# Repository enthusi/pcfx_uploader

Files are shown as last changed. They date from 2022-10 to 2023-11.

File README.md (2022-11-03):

# PCFX Uploader
transmitting data from PC to a NEC PC-FX via microcontroller in GPL v3 licence.

## Build
*microcontroller_code* contains the firmware in assembly for the LonganNano.\
*RP2040_device* contains information on how to build an alternate microcontroller board, and firmware (C & PIO Assembly) for this board.\
*pc_code* with the python script to upload data via UART connection.\
*pcfx_code* contains the client on NEC PC-FX side in v810 assembly (`make cd` will build an CD bin/cue image).

To build just type ```make``` in the corresponding folder, or launch the script, given that you have the following tools in your path:\
[RV32 Assembler Bronzebeard](https://github.com/theandrew168/bronzebeard)\
[v810 binutils](https://github.com/jbrandwood/v810-gcc)\
[pcfx-tools](https://github.com/jbrandwood/pcfxtools)

The RP2040 device is based on pico-sdk version 1.4.0.  To build, execute the command within 'build_xiao.sh', then 'cd build', and 'make'\
[pico-sdk](https://github.com/raspberrypi/pico-sdk)

## Summary
- the code on the PCFX side expects a magic word, start-address, execution-address and data length
- the code on the microcontroller mimics a PC-FX controller and sends all 32 keypad bits in the PC-FX specific protocol
- the code on the PC side simply connects to the microcontroller via UART
- The overall transmission speed is close to the UART limit despite a couple of extended wait loops on the PC-FX side. That could be optimized for speed if one really wanted to.

## Setup

### Longan Nano
This setup was used for initial development. The RP2040-based board will become the main supported plattform.\
The Longan Nano is hooked up to Port2 of the PC-FX via 3V-5V level shifts (though it _should_ be 5V tolerant)\
It uses 5 lines: GND, VCC, CLOCK, LATCH and DATA.\
The PC-FX pulls the LATCH line to low (0 Volts) when it wants more data to come in.
Then it sends a quick clock signal HIGH,LOW,HIGH,...\
The microcontroller senses that LATCH line, if it gets low, waits for it to get high then senses the CLOCK line and makes sure to put the proper
signal on the output DATA depending on the state of your data bit (0 or 1). Initially, I tested that in C on the raspberry PI with _some_ success.
But it became clear that it would be too instable. Then I went for a microcontroller (with only ~100 Mhz) in C. That worked but I wasn't totally happy.
Then I recoded the microcontroller in plain assembly (32bit RiscV, not too different from the PC-FX's native v810 CPU btw).
The PC connects via UART to the native UART lines of the Longan Nano.

### RP2040-based board
This operates the same as the Longan Nano, except observes the /OE line, which was found to control the direction of data on the DATA line (which
means that data can flow both *to* and *from* the PC-FX).
When this signal is high, the PC-FX sends data, so the microcontroller's output data line is tri-stated, and the signal is routed to an
alternate pin to be used for inbound data.
PIO assembly language is used for signal switching at high speeds, as this is its strength; the 'C' code merely acts as a traffic manager
for the data.
On this board, the USB port is used a virtual COM port, in order to keep the parts count to a minimum.

## Demonstration
YouTube recording of initial LonganNano variant:\
NEC PC-FX uploader by PriorArt (https://www.youtube.com/watch?v=flS91IILcIk "NEC PC-FX uploader by PriorArt")

## Credits
- PC-FX code and Longan board design and code: *Martin 'enthusi' Wendt* [PriorArt](https://priorartgames.eu)
- RP2040 board design and code: *David Shadoff*

the folder *pc_code* contains the PC-FX binary `mandelbrot` from
[PC-FX Mandelbrot](https://github.com/enthusi/pcfx_fractal) which you can use to send as an example `python pysend.py mandelbrot`.\
See also: [PriorArt website](https://priorartgames.eu/2022/10/03/demo-mandelbrot-for-nec-pc-fx/)

## Research
[David Shadoff](https://github.com/dshadoff) tested the signals from '[test data line release'](https://github.com/enthusi/pcfx_uploader/releases/tag/testing_output) based on a RP2040 setup with his logic analyzer and confirms our expectation, that the data line is indeed bidirectional. Also the OE signal change flags the used direction.\
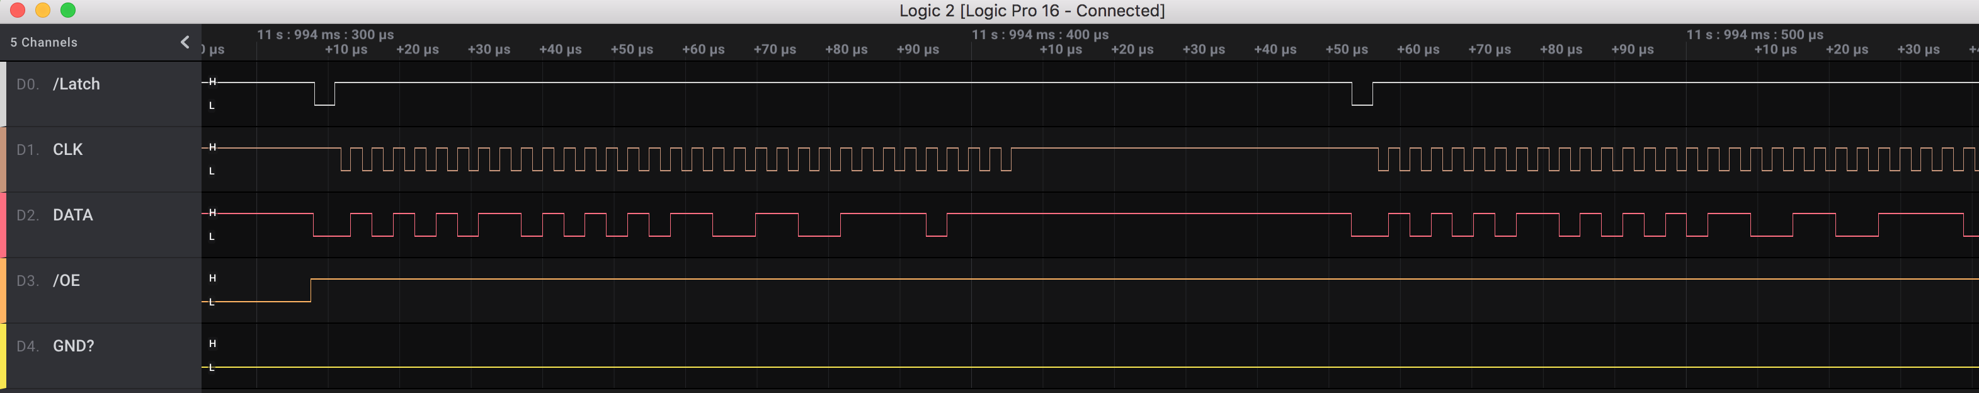
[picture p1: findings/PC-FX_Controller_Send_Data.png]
Logic analyzer


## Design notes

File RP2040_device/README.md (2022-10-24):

# PCFX Uploader RP2040 Device

## Overview

This section of the repository includes PC Board designs and instructions for building a PC-FX communications device, and
also includes the firware in order to work in concert with the PC-FX and PC components elsewhere in this repository.
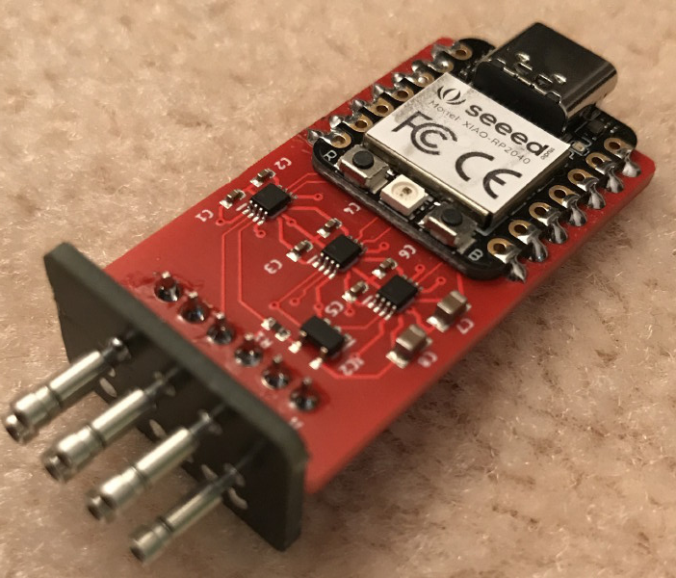
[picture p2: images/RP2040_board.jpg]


## PC Boards and Assembly

I designed all boards using the free version of EAGLE (2-layer, less than 100mm on both X- and Y- axes).
The gerbers are included in this repository, in case you want to get your own set made.

I have included the gerbers and relevant bom.csv and assembly.csv files to get these boards
assembled by JLCPCB, but you will still need the following parts:
- (1) Seeed Studio XIAO RP2040 microcontroller board
- (1) 6-pin right-angle through-hole pin header with 0.1" spacing.
- (7) Mill-Max Manufacturing part number 4401-0-15-80-18-27-04-0 "Receptacle with a standard tail" for creating a custom controller connector.
These are available at Digi-Key/Mouser.

You may also want to use male/female pin header sockets in case you need to remove the microcontroller board.
I recommend using short/low-profile header sockets in this case.

... These boards are solderable along the castellation, which is the recommended approach for assembly.

### Steps to assembly - Connector Board

Soldering the connector has a slightly more complicated process than the microcontroller board.  It's best not to have the pins penetrate all
the way through the board.  This is how I do it:
1. Insert the 7 Mill-Max connector pins into the PC-FX connector; you can use a pair of needle-nose pliers to assist in positioning.
2. Make sure to have one or two strands of speaker wire between the rows of pins; these will be used to extract the connector when
soldering is complete, but this wire should not be soldered to any part of the connector.
3. Position the connector board on top of the pins so that the silkscreen printing is facing up. Allow the pins to penetrate the holes slightly
but try to have them remain nearly flush with the PC board.
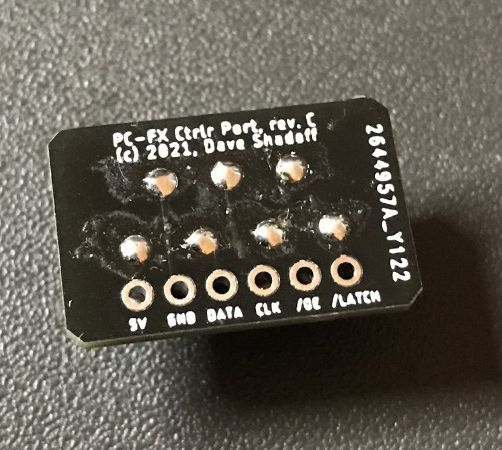
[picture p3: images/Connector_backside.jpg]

4. Ensure that the empty row of pins (which we will use for the right-angle pin headers) is not so close to the PC-FX; we would not want
them to be shorted by the slightly-visible metal faceplate when inserted.
5. Solder the pins in place
6. Use the wire to carefully extract the connectr assembly.
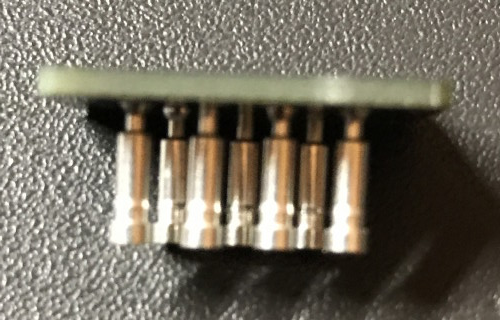
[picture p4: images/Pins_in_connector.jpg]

7. For the right-angle pin header, use angle clippers to remove some of the height of the pins so that they don't emerge through the
other side of the board when inserted.  The board should be 1.6mm thick; roughly 1.2mm-1.5mm of pin should be sufficient.
8. Solder the pin headers into place, with the long end facing inward; these will hold the main board in place.
9. Keep the solder on these holes as flat as possible; there is an opportunity to apply nail polish or some other NON-CONDUCTIVE
coating to ensure that they don't get shorted out by any metal hear the connector socket.

### Steps to assembly - RP2040 Board

1. Position the Seed RP2040 board on the top side carrier board (where other parts are also mounted), such that the holes are aligned
(you may wish to use a pin header or two to anchor it in place). Solder the boards together at the castellation as shown in the photo.
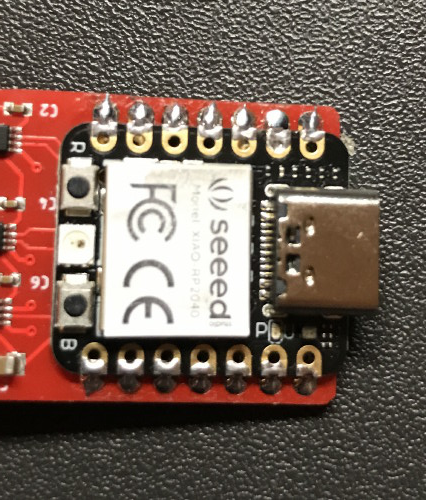
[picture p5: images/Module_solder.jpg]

2. Insert the headers from the connector board through the holes on the RP2040 board.  Be careful to ensure that the pins are on the
opposite side from the parts (i.e. the pins seem to "emerge" upwards when looking at the 'top' of the board where the parts are mounted).
This connection should be tight enough that the pins can hold the board in place.
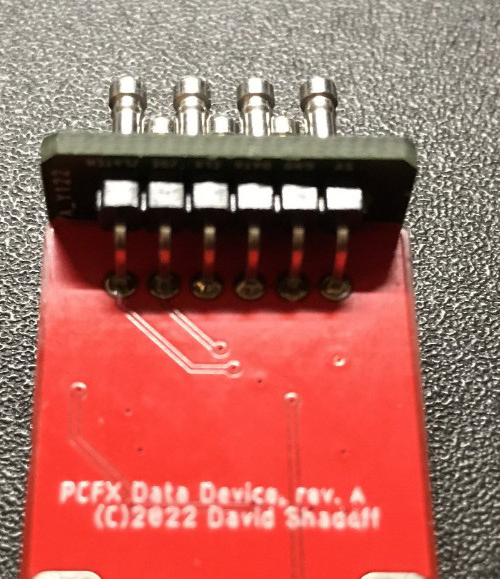
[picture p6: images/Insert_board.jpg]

3. With the board positioned roughly midway between the rows of the connector pins, solder the header pins into place.
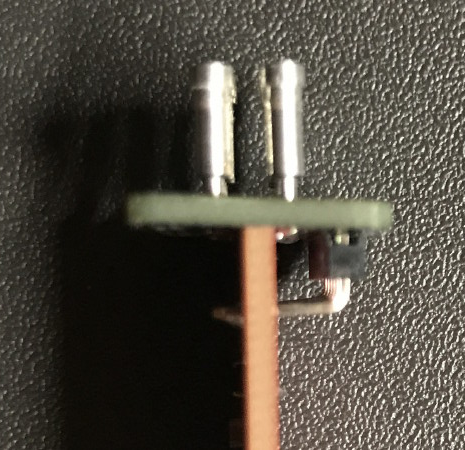
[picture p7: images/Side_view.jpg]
Top View

4. Program the microncontroller board accroudng to the steps in "Programming the Microcontroller Board" below.

## Source Code

### Compilation

This code was built to use Pico-SDK version 1.4.0, which may not be the newest version when you read this, but shouldn't have any
features which will change in futue versions (although it requires some components which were only made available in 1.4.0, so is
not backward-compatible).

pico_sdk_import.cmake is from the SDK, but is required by CMake (and thus replicated here)

This is based on the TinyUSB Host HID example, and since this often changes (required by refactoring of
the Host HID code), the initial commit baseline is the source ocde of that example.

To build the source, first ensure that you have the right version of the RaspberryPi/piso-sdk installed.
As this board targets the Seeed Studio XIAO RP2040 board, you should run the "make_xiao.sh" script (under UNIX).
Then, "cd build" and "make".

### Programming the Microcontroller Board

I have also included a release version of the program as a uf2 file in the releases/ folder.

To put the device into BOOTSEL mode, the board must be rebooted with the 'Boot' button pressed.  This can be done one of two ways:
1. Press and hold the button marked as 'B' (boot) while the USB is connected to a computer (and then release after power is applied), OR
2. Connect the USB to a computer, then press and hold the button marked as 'B' (boot), and while continuing to hold that button, press and
release the button marked as 'R' (reset).
The board will reboot in DFU mode, and will present itself as a USB drive to the host PC.

Then, just drag and drop the .uf2 file onto the USB drive which is presented.

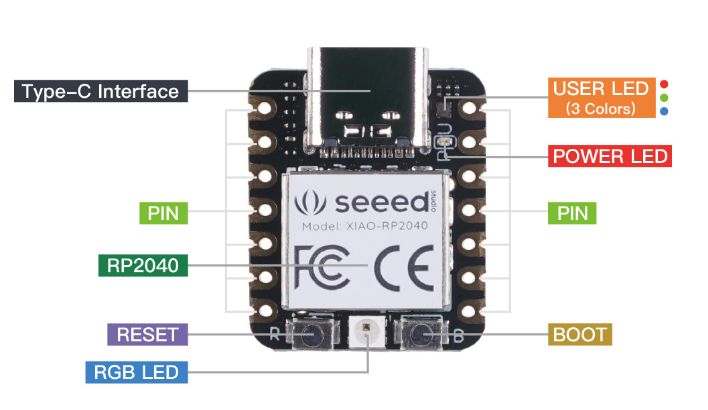
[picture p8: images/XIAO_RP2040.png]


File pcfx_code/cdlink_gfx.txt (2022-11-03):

binary loader_gfx
name framework
maker enthusi
makerid n2c
date 20220728
country 1
version 1

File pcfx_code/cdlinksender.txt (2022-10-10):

binary sender
name framework
maker enthusi
makerid n2c
date 20221010
country 1
version 1

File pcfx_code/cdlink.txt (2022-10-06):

binary loader
name framework
maker enthusi
makerid n2c
date 20220728
country 1
version 1

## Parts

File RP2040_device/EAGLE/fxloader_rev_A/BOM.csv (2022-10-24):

Qty | Designator | Footprint | Comment | LCSC Part # (optional) | Description (optional)
1 | J1 | 1X06_NO_SILK | Do not mount | Do not mount | Multi connection point. Often used as Generic Header-pin footprint for 0.1 inch spaced/style header connections
1 | J5 | 1X07_LONGPADS_OFFSET | Do not mount | Do not mount | Multi connection point. Often used as Generic Header-pin footprint for 0.1 inch spaced/style header connections
1 | J4 | 1X07_LONGPADS_OFFSET_B | Do not mount | Do not mount | Multi connection point. Often used as Generic Header-pin footprint for 0.1 inch spaced/style header connections
6 | C1, C2, C3, C4, C5, C6 | C0402 | 100nF 16V | C1525 | Samsung CL05B104KO5NNNC 100nF 16V 0402
2 | C7, C8 | C0805 | 10uF 25V | C15850 | Samsung CL21A106KAYNNNE 10uF 25V 0805
1 | R1 | R0402 | 330R | C25104 | Uniroyal Elec 0402WGF3300TCE 0402
1 | IC2 | SOT-23-5 | SN74AHCT1G125DBVR | C7484 | 74AHCT Single Tri-state Bus Buffer SOT23 SN74AHCT1G125DBVR, Bus Buffer, HCT, 8.5 ns@ 50 pF, 8mA 4.5 ??? 5.5 V 5-Pin SOT-23
3 | IC1, IC3, IC4 | VSSOP-8_2.0x2.3x0.5P | SN74LVC2T45DCUR | C15741 | 2-Bit Bus Transceiver, Translation VSSOP-8_2x2.3x05P SN74LVC2T45DCTR, Voltage Level Translator, Bus Transceiver LVC, 3-State 1.65

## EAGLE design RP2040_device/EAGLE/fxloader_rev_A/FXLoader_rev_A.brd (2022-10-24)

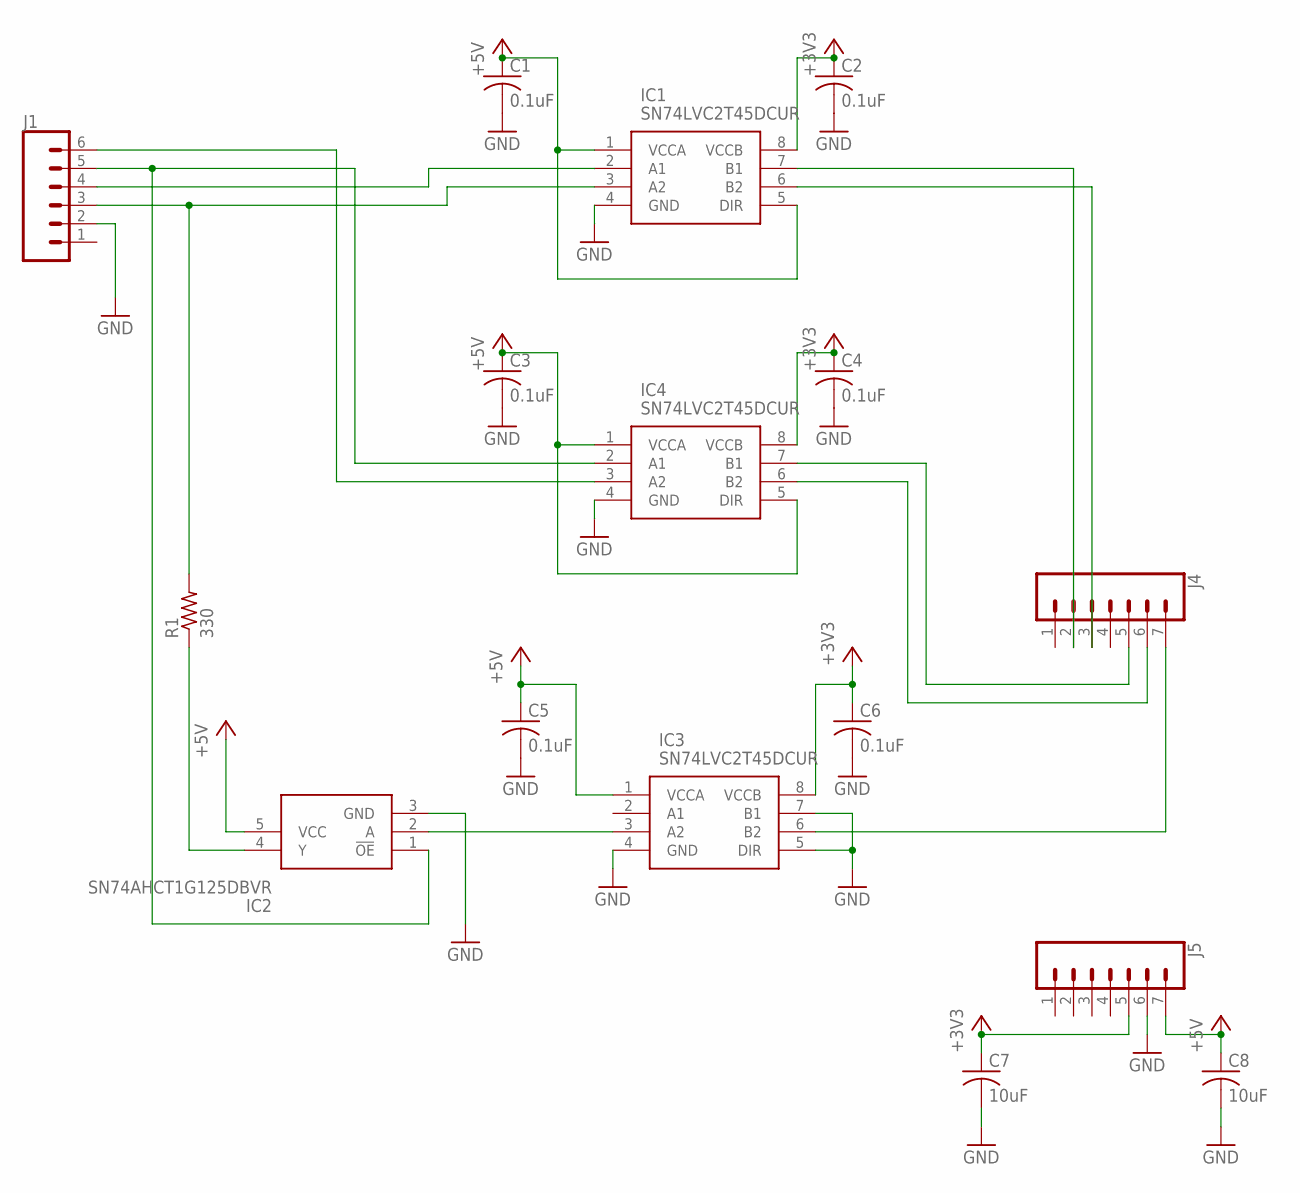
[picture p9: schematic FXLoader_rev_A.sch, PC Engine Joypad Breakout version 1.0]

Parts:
C1, C2, C3, C4, C5, C6: 0.1uF; C0402
C7, C8: 10uF; C0805
IC1, IC3, IC4: SN74LVC2T45DCUR; SOP50P310X90-8N
IC2: SN74AHCT1G125DBVR; SOT95P280X145-5N
J1: CONN_06NO_SILK_FEMALE_PTH; 1X06_NO_SILK
J4: CONN_071X07_LONGPADS_OFFSET_B; 1X07_LONGPADS_OFFSET_B
J5: CONN_071X07_LONGPADS_OFFSET; 1X07_LONGPADS_OFFSET
R1: 330; R0402

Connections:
+3V3: C2.1, C4.1, C6.1, C7.1, IC1.8 (VCCB), IC3.8 (VCCB), IC4.8 (VCCB), J5.5
+5V: C1.1, C3.1, C5.1, C8.1, IC1.1 (VCCA), IC1.5 (DIR), IC2.5 (VCC), IC3.1 (VCCA), IC4.1 (VCCA), IC4.5 (DIR), J5.7
CLK: IC1.2 (A1), J1.4
DATA: IC1.3 (A2), J1.3, R1.2
GND: C1.2, C2.2, C3.2, C4.2, C5.2, C6.2, C7.2, C8.2, IC1.4 (GND), IC2.3 (GND), IC3.4 (GND), IC3.5 (DIR), IC3.7 (B1), IC4.4 (GND), J1.2, J5.6
unnamed: IC2.2 (A), IC3.3 (A2)
unnamed: IC1.7 (B1), J4.2
unnamed: IC3.6 (B2), J4.7
unnamed: IC2.4 (Y), R1.1
unnamed: IC4.3 (A2), J1.6
unnamed: IC4.6 (B2), J4.6
unnamed: IC1.6 (B2), J4.3
unnamed: IC4.7 (B1), J4.5
W/R: IC2.1 (!OE), IC4.2 (A1), J1.5

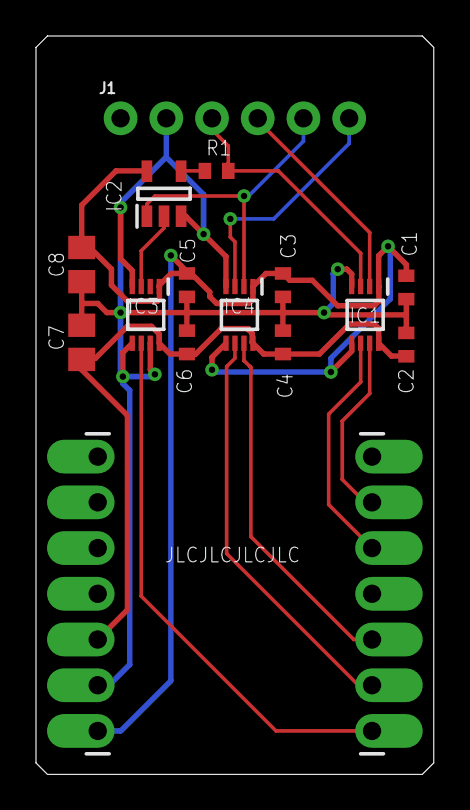
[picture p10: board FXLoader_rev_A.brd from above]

Board: 2 copper layers, 22.1 x 41.0 mm, 16 parts (0 on the bottom side), 14 nets.

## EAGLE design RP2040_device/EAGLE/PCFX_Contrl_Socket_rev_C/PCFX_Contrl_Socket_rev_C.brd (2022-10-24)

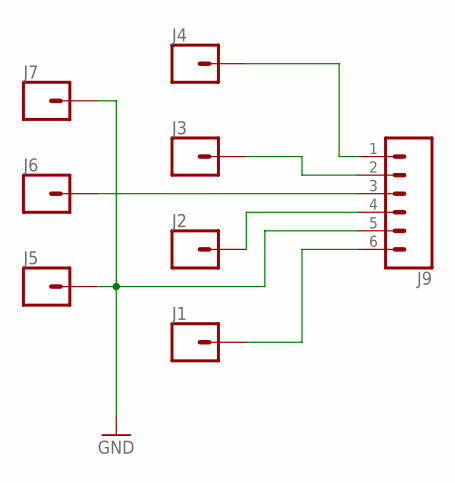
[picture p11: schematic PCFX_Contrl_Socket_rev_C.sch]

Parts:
J1, J2, J3, J4, J5, J6, J7: CONN_01PTH_NO_SILK_YES_STOP; 1X01_NO_SILK
J9: CONN_06NO_SILK_FEMALE_PTH; 1X06_NO_SILK

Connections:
GND: J5.1, J7.1, J9.5
unnamed: J4.1, J9.1
unnamed: J3.1, J9.2
unnamed: J6.1, J9.3
unnamed: J2.1, J9.4
unnamed: J1.1, J9.6

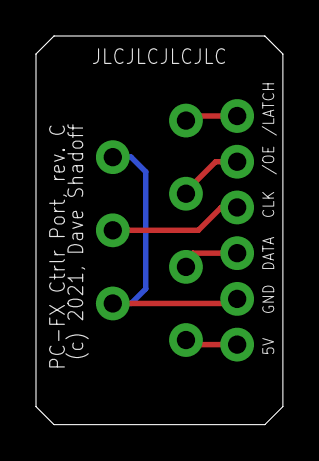
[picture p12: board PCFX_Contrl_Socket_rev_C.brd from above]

Board: 2 copper layers, 13.7 x 21.6 mm, 8 parts (0 on the bottom side), 6 nets.

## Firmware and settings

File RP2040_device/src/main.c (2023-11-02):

/**
 * Copyright (c) 2020 Raspberry Pi (Trading) Ltd.
 *
 * SPDX-License-Identifier: BSD-3-Clause
 */

#include <stdio.h>

#include "pico/stdlib.h"
#include "hardware/pio.h"
#include "hardware/uart.h"
#include "pcfxplex.pio.h"
#include "clock.pio.h"
#include "ws2812.pio.h"

//--------------------------------------------------------------------+
// MACRO CONSTANT TYPEDEF PROTYPES
//--------------------------------------------------------------------+


#define UART_ID uart0
#define BAUD_RATE 115200

// We are using pins 0 and 1, but see the GPIO function select table in the
// datasheet for information on which other pins can be used.
#define UART_TX_PIN 0
#define UART_RX_PIN 1


#define IS_RGBW false
#define NUM_PIXELS 1

#define LED_UART_TO_MCU   urgb_u32(0,10,0)   // green
#define LED_MCU_TO_PCFX   urgb_u32(0,0,10)   // blue
#define LED_PCFX_TO_MCU   urgb_u32(10,0,0)   // red
#define LED_MCU_TO_UART   urgb_u32(10,10,0)  // yellow
#define LED_EXEC          urgb_u32(3,0,3)    // purple
#define LED_IDLE          urgb_u32(5,5,5)    // light white


#ifdef SEEED_XIAO_RP2040         // else assignments for Seed XIAO RP2040 board

#define DATAIN_PIN      6
#define CLKIN_PIN       DATAIN_PIN + 1
#define DATAOUT_PIN     26
#define LATCHIN_PIN     27
#define READWRITE_PIN   28       // determines data direction

#define PICO_LED1       17
#define PICO_LED2       16
#define PICO_LED3       25
#define PICO_LED_ON     0
#define PICO_LED_OFF    1

#define WS2812_PIN PICO_DEFAULT_WS2812_PIN

#endif


uint32_t magic_word = 0x12345678; // for deploying initial program

uint32_t read_word = 0x44414552;  // READ
uint32_t rdbr_word = 0x52424452;  // RDBR
uint32_t writ_word = 0x54495257;  // WRIT
uint32_t wrbr_word = 0x52425257;  // WRBR
uint32_t exec_word = 0x43455845;  // EXEC
uint32_t call_word = 0x4C4C4143;  // CALL

uint32_t start_addr = 0x00008000;
uint32_t num_bytes  = 0;

uint32_t payload_data[32768];


PIO pio, pioled;
uint sm1, sm2, smled;   // sm1 = plex, sm2 = clock


//// WS2812 "Neopixel" protocol transport
//
static inline void put_pixel(uint32_t pixel_grb) {
    pio_sm_put_blocking(pioled, smled, pixel_grb << 8u);
}

static inline uint32_t urgb_u32(uint8_t r, uint8_t g, uint8_t b) {
    return
            ((uint32_t) (r) << 8) |
            ((uint32_t) (g) << 16) |
            (uint32_t) (b);
}

/// UART
//
uint8_t uart_get_char(void)
{
int inchar;

   inchar = getchar_timeout_us(0);
//   inchar = uart_getc(UART_ID);

   while (inchar == PICO_ERROR_TIMEOUT)
      inchar = getchar_timeout_us(0);

   return((uint8_t)inchar);
}

//
// Find the 'magic word' by scanning the UART stream first for the initial byte,
// and then checking whether the next 3 bytes form the word; if not, then start over
//
uint32_t uart_get_magic_word(void)
{
uint32_t uart_word = 0;
uint8_t  uart_byte = 0;

   while (uart_word != magic_word) {
      uart_word = 0;

      while (uart_byte != (uint8_t)(magic_word & 0xff))
         uart_byte = uart_get_char();

      uart_word |= uart_byte;

      uart_byte = uart_get_char();
      uart_word |= (uart_byte << 8);

      uart_byte = uart_get_char();
      uart_word |= (uart_byte << 16);

      uart_byte = uart_get_char();
      uart_word |= (uart_byte << 24);
   }

   return(uart_word);
}

uint32_t uart_get_cmd(void)
{
uint32_t uart_word = 0;
uint8_t  uart_byte = 0;
bool     word_match = false;

   while (!word_match)
   {
     uart_byte = uart_get_char();

     uart_word = ((uart_word >> 8) & 0xffffff) | (uart_byte << 24);

     if ((uart_word == read_word) ||
         (uart_word == rdbr_word) ||
         (uart_word == writ_word) ||
         (uart_word == wrbr_word) ||
         (uart_word == exec_word) ||
         (uart_word == call_word))
     {
        word_match = true;
     }
   }
   return(uart_word);
}

uint32_t uart_get_word(void)
{
uint32_t uart_word = 0;
uint8_t  uart_byte = 0;

   uart_byte = uart_get_char();
   uart_word |= uart_byte;

   uart_byte = uart_get_char();
   uart_word |= (uart_byte << 8);

   uart_byte = uart_get_char();
   uart_word |= (uart_byte << 16);

   uart_byte = uart_get_char();
   uart_word |= (uart_byte << 24);

   return(uart_word);
}


void __not_in_flash_func(write_type_cmd)(uint32_t fx_command)
{
uint32_t start_addr;
uint32_t num_bytes;
uint32_t outword;
uint32_t junk;
int index = 0;
int count;

    put_pixel(LED_UART_TO_MCU);
    sleep_ms(10);

    start_addr  = uart_get_word();
    num_bytes   = uart_get_word();

    count = num_bytes;

    while(count > 0) {
      payload_data[index++] = uart_get_word();
      count -= 4;
    }

    put_pixel(LED_MCU_TO_PCFX);
    sleep_ms(10);

    // drain RX FIFO in case it has residual junk
    //
    while (!pio_sm_is_rx_fifo_empty(pio, sm1)) {
       junk = pio_sm_get_blocking(pio, sm1);
    }
    
    // note that PC-FX inverts on input, so we need to send all data as 1's complement
    outword = ~fx_command;
    pio_sm_put_blocking(pio, sm1, outword);

    outword = ~start_addr;
    pio_sm_put_blocking(pio, sm1, outword);

    outword = ~num_bytes;
    pio_sm_put_blocking(pio, sm1, outword);

    count = (num_bytes / 4);
    if ((num_bytes & 3) != 0)
       count++;

    for (index = 0; index < count; index++) {
       outword = ~payload_data[index];
       pio_sm_put_blocking(pio, sm1, outword);
    }

    // Output acknowledgement "word"
    putchar_raw((int)0);

    sleep_ms(10);

    // clear FIFOs in case of junk
    pio_sm_clear_fifos(pio, sm1);
}

void __not_in_flash_func(read_type_cmd)(uint32_t fx_command)
{
uint32_t start_addr;
uint32_t num_bytes;
uint32_t outword;
uint32_t inword, indata;
uint32_t junk;
uint32_t count = 0;
uint32_t index = 0;
int i = 0;

    start_addr  = uart_get_word();
    num_bytes   = uart_get_word();

    put_pixel(LED_PCFX_TO_MCU);
    sleep_ms(10);

    // drain RX FIFO in case it has residual junk
    //
    while (!pio_sm_is_rx_fifo_empty(pio, sm1)) {
       junk = pio_sm_get_blocking(pio, sm1);
    }
    
    // ------------
    // send request
    // ------------

    // note that PC-FX inverts on input, so we need to send all data as 1's complement
    outword = ~fx_command;
    pio_sm_put_blocking(pio, sm1, outword);

    outword = ~start_addr;
    pio_sm_put_blocking(pio, sm1, outword);

    outword = ~num_bytes;
    pio_sm_put_blocking(pio, sm1, outword);

    // ----------------
    // receive response
    // ----------------

    // Ignore first word returned from PC-FX; for some reason the PC-FX side has
    // an issue with the first word written after reading data; it occasionally
    // retains and sends out the lower half-word of the last inbound word.
    //
    // So, we send a dummy word to 'flush' the potentially bad data.
    //
    junk = pio_sm_get_blocking(pio, sm1);

    count = num_bytes/4;
    index = 0;

    while(index < count) {
      inword = pio_sm_get_blocking(pio, sm1);
      indata = ~inword;

      if ((index == 0) && (indata & 0x0000ffff) == (num_bytes & 0x0000ffff))
         gpio_put(PICO_LED2, PICO_LED_ON);

      payload_data[index++] = indata;
    }

    sleep_ms(10);
    put_pixel(LED_MCU_TO_UART);

    for (i = 0; i < count; i++) {
      putchar_raw((int)(payload_data[i] & 0xff));
      putchar_raw((int)((payload_data[i] >> 8) & 0xff));
      putchar_raw((int)((payload_data[i] >> 16) & 0xff));
      putchar_raw((int)((payload_data[i] >> 24) & 0xff));
      sleep_us(100);
    }

    sleep_ms(10);

    // clear FIFOs in case of junk
    pio_sm_clear_fifos(pio, sm1);
}

void __not_in_flash_func(exec_type_cmd)(uint32_t fx_command)
{
uint32_t exec_addr;
uint32_t outword;
uint32_t junk;

    put_pixel(LED_EXEC);
    exec_addr  = uart_get_word();

    // drain RX FIFO in case it has residual junk
    //
    while (!pio_sm_is_rx_fifo_empty(pio, sm1)) {
       junk = pio_sm_get_blocking(pio, sm1);
    }
    
    // note that PC-FX inverts on input, so we need to send all data as 1's complement
    outword = ~fx_command;
    pio_sm_put_blocking(pio, sm1, outword);

    outword = ~exec_addr;
    pio_sm_put_blocking(pio, sm1, outword);

    sleep_ms(10);

    // clear FIFOs in case of junk
    pio_sm_clear_fifos(pio, sm1);
}

void __not_in_flash_func(get_cmd_from_uart)(void)
{
uint32_t fx_command;

    put_pixel(LED_IDLE);
    sleep_ms(10);

    fx_command = uart_get_cmd();

    pio_sm_clear_fifos(pio, sm1);  // in case startup placed junk in FIFOs
    pio_sm_clear_fifos(pio, sm1);  // in case it was blocked on PUSH (one last word to drain)

    if ((fx_command == read_word) || (fx_command == rdbr_word))
    {
       read_type_cmd(fx_command);
    }
    else if ((fx_command == writ_word) || (fx_command == wrbr_word))
    {
       write_type_cmd(fx_command);
    }
    else if ((fx_command == exec_word) || (fx_command == call_word))
    {
       exec_type_cmd(fx_command);
    }
}


void ws2812_countdown()
{
int start = 25;
int count;

    for (count = start; count >= 0; count--) {
      put_pixel(urgb_u32(count, 0, 0));  // red
      sleep_ms(10);
    }
    sleep_ms(200);

    for (count = start; count >= 0; count--) {
      put_pixel(urgb_u32(0, count, 0));  // green
      sleep_ms(10);
    }
    sleep_ms(200);

    for (count = start; count >= 0; count--) {
      put_pixel(urgb_u32(0, 0, count));  // blue
      sleep_ms(10);
    }
    sleep_ms(200);

    put_pixel(LED_IDLE);  // light white
}

int main() {

int a;
uint32_t outword;

int count = 0;

    stdio_init_all();

//// UART
    // Set up our UART with the required speed.
    uart_init(UART_ID, BAUD_RATE);
    uart_set_translate_crlf(UART_ID, false);

    // Set the TX and RX pins by using the function select on the GPIO
    // Set datasheet for more information on function select
    gpio_set_function(UART_TX_PIN, GPIO_FUNC_UART);
    gpio_set_function(UART_RX_PIN, GPIO_FUNC_UART);
////

////////////////////////
// Turn off regular LEDs
//
    gpio_init(PICO_LED1);  // red   LED
    gpio_init(PICO_LED2);  // green LED
    gpio_init(PICO_LED3);  // blue  LED

    gpio_set_dir(PICO_LED1, GPIO_OUT);
    gpio_set_dir(PICO_LED2, GPIO_OUT);
    gpio_set_dir(PICO_LED3, GPIO_OUT);

    gpio_put(PICO_LED1, PICO_LED_OFF);
    gpio_put(PICO_LED2, PICO_LED_OFF);
    gpio_put(PICO_LED3, PICO_LED_OFF);

////////////////////////
// Setup NeoPixel LED
//
    gpio_init(PICO_DEFAULT_WS2812_POWER_PIN);
    gpio_set_dir(PICO_DEFAULT_WS2812_POWER_PIN, GPIO_OUT);
    gpio_put(PICO_DEFAULT_WS2812_POWER_PIN, 1);

    pioled = pio1;
    smled = 0;

    uint offset = pio_add_program(pioled, &ws2812_program);

    ws2812_program_init(pioled, smled, offset, WS2812_PIN, 800000, IS_RGBW);

//////////////////////////////////////

    // Both communications state machines run on one PIO processor (but LED on other)
    pio = pio0;

    sleep_ms(200);  // allow GPIO values to settle before initating PIOs

    // Load the plex (multiplex output) program, and configure a free state machine
    // to run the program.

    uint offset1 = pio_add_program(pio, &pcfxplex_program);
    sm1 = pio_claim_unused_sm(pio, true);
    pcfxplex_program_init(pio, sm1, offset1, DATAIN_PIN, DATAOUT_PIN, READWRITE_PIN);

    uint offset2 = pio_add_program(pio, &clock_program);
    sm2 = pio_claim_unused_sm(pio, true);
    clock_program_init(pio, sm2, offset2, LATCHIN_PIN);


// wait at startup
//
    sleep_ms(1500);

    pio_sm_clear_fifos(pio, sm1);  // in case startup placed junk in FIFOs
    pio_sm_clear_fifos(pio, sm1);  // in case it was blocked on PUSH (one last word to drain)

    outword = ~0;
    pio_sm_put_blocking(pio, sm1, outword);

// Now flash LED(s) to signify all is well
//
    ws2812_countdown();

    sleep_ms(200);

    while(1) {
      get_cmd_from_uart();
    }

    return 0;
}

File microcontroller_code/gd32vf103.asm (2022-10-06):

# GD32VF103 Manual: Section 5.3
RCU_BASE_ADDR = 0x40021000

# GD32VF103 Manual: Section 5.3.7
RCU_APB2EN_OFFSET   = 0x18
RCU_APB2EN_AFEN_BIT = 0
RCU_APB2EN_PAEN_BIT = 2
RCU_APB2EN_PBEN_BIT = 3
RCU_APB2EN_PCEN_BIT = 4
RCU_APB2EN_PDEN_BIT = 5
RCU_APB2EN_PEEN_BIT = 6
RCU_APB2EN_SPI0EN_BIT = 12
RCU_APB2EN_USART0EN_BIT = 14

RCU_APB2EN_SPI0EN = (1 << RCU_APB2EN_SPI0EN_BIT )

# GD32VF103 Manual: Section 7.5
AFIO_BASE_ADDR   = 0x40010000

GPIO_BASE_ADDR_A = 0x40010800  # GD32VF103 Manual: Section 7.5 (green and blue LEDs)
GPIO_BASE_ADDR_B = 0x40010C00
GPIO_BASE_ADDR_C = 0x40011000  # GD32VF103 Manual: Section 7.5 (red LED)
GPIO_BASE_ADDR_D = 0x40011400 
GPIO_BASE_ADDR_E = 0x40011800 

GPIO_CTL0_OFFSET  = 0x00 # GPIO port control register 0
GPIO_CTL1_OFFSET  = 0x04 # GPIO port control register 1
GPIO_ISTAT_OFFSET = 0x08 # GPIO port input status register
GPIO_OCTL_OFFSET  = 0x0C # GPIO port output control register
GPIO_BOP_OFFSET   = 0x10 # GPIO port bit operation register
GPIO_BC_OFFSET    = 0x14 # GPIO bit clear register 

# GD32VF103 Manual: Section 7.3
GPIO_MODE_IN        = 0b00
GPIO_MODE_OUT_10MHZ = 0b01
GPIO_MODE_OUT_2MHZ  = 0b10
GPIO_MODE_OUT_50MHZ = 0b11

# GD32VF103 Manual: Section 7.3
GPIO_CTL_IN_ANALOG    = 0b00
GPIO_CTL_IN_FLOATING  = 0b01
GPIO_CTL_IN_PULL_DOWN = 0b10
GPIO_CTL_IN_PULL_UP   = 0b11

# GD32VF103 Manual: Section 7.3
GPIO_CTL_OUT_PUSH_PULL      = 0b00
GPIO_CTL_OUT_OPEN_DRAIN     = 0b01
GPIO_CTL_OUT_ALT_PUSH_PULL  = 0b10
GPIO_CTL_OUT_ALT_OPEN_DRAIN = 0b11

# combined CTL[1:0], MD[1:0]  for config and mode
GPIO_MODE_IN_ANALOG   = 0x0 #  analog input 
GPIO_MODE_PP_10MHZ    = 0x1 #  push-pull output, max speed 10MHz
GPIO_MODE_PP_2MHZ     = 0x2 #  push-pull output, max speed 2MHz
GPIO_MODE_PP_50MHZ    = 0x3 #  push-pull output, max speed 50MHz
GPIO_MODE_IN_FLOAT    = 0x4 #  floating input 
GPIO_MODE_OD_10MHZ    = 0x5 #  open-drain output, max speed 10MHz
GPIO_MODE_OD_2MHZ     = 0x6 #  open-drain output, max speed 2MHz
GPIO_MODE_OD_50MHZ    = 0x7 #  open-drain output, max speed 50MHz
GPIO_MODE_IN_PULL     = 0x8 #  input with pull up/down

GPIO_MODE_AF_PP_10MHZ = 0x9 #  alternate function push-pull, max speed 10MHz
GPIO_MODE_AF_PP_2MHZ  = 0xa #  alternate function push-pull, max speed 2MHz
GPIO_MODE_AF_PP_50MHZ = 0xb #  alternate function push-pull, max speed 50MHz
GPIO_MODE_AF_OD_10MHZ = 0xd #  alternate function open-drain, max speed 10MHz
GPIO_MODE_AF_OD_2MHZ  = 0xe #  alternate function open-drain, max speed 2MHz
GPIO_MODE_AF_OD_50MHZ = 0xf #  alternate function open-drain, max speed



# GD32VF103 Manual: Section 16.4
USART_BASE_ADDR_0 = 0x40013800

# GD32VF103 Manual: Section 16.4.1
USART_STAT_OFFSET   = 0x00
USART_STAT_RBNE_BIT = 5
USART_STAT_TBE_BIT  = 7

# GD32VF103 Manual: Section 16.4.2
USART_DATA_OFFSET = 0x04

# GD32VF103 Manual: Section 16.4.3
USART_BAUD_OFFSET = 0x08

# GD32VF103 Manual: Section 16.4.4
USART_CTL0_OFFSET = 0x0c
USART_CTL0_REN_BIT = 2
USART_CTL0_TEN_BIT = 3
USART_CTL0_UEN_BIT = 13

  
RCU_BASE_ADDR      = 0x40021000  # GD32VF103 Manual: Section 5.3
RCU_CTL_OFFSET     = 0x00  
RCU_CFG0_OFFSET    = 0x04
RCU_INT_OFFSET     = 0x08
RCU_APB2RST_OFFSET = 0x0c
RCU_APB1RST_OFFSET = 0x10
RCU_AHBEN_OFFSET   = 0x14
RCU_APB2EN_OFFSET  = 0x18  # GD32VF103 Manual: Section 5.3.7
RCU_APB1EN_OFFSET  = 0x1c
RCU_BDCTL_OFFSET   = 0x20
RCU_RSTSCK_OFFSET  = 0x24
RCU_AHBRST_OFFSET  = 0x28
RCU_CFG1_OFFSET    = 0x2c 
RCU_APB2RST_SPI0RST = (1<<12) #SPI0 reset 

RCU_APB2EN_AFEN = (1<<0) #AF enable reset 

# GD32VF103 Manual: Section 5.3.7
RCU_APB2EN_OFFSET = 0x18

RCU_APB2EN_USART0EN_BIT = 14
RCU_APB2EN_SPI0EN_BIT   = 12
RCU_APB2EN_TIMER0EN_BIT = 11
RCU_APB2EN_ADC1EN_BIT   = 10
RCU_APB2EN_ADC0EN_BIT   = 9
RCU_APB2EN_PEEN_BIT     = 6
RCU_APB2EN_PDEN_BIT     = 5
RCU_APB2EN_PCEN_BIT     = 4
RCU_APB2EN_PBEN_BIT     = 3
RCU_APB2EN_PAEN_BIT     = 2
RCU_APB2EN_AFEN_BIT     = 0

RCU_APB2EN_USART0EN = (1 << RCU_APB2EN_USART0EN_BIT)
RCU_APB2EN_SPI0EN   = (1 << RCU_APB2EN_SPI0EN_BIT)
RCU_APB2EN_TIMER0EN = (1 << RCU_APB2EN_TIMER0EN_BIT)
RCU_APB2EN_ADC1EN   = (1 << RCU_APB2EN_ADC1EN_BIT)
RCU_APB2EN_ADC0EN   = (1 << RCU_APB2EN_ADC0EN_BIT)
RCU_APB2EN_PEEN     = (1 << RCU_APB2EN_PEEN_BIT)
RCU_APB2EN_PDEN     = (1 << RCU_APB2EN_PDEN_BIT)
RCU_APB2EN_PCEN     = (1 << RCU_APB2EN_PCEN_BIT)
RCU_APB2EN_PBEN     = (1 << RCU_APB2EN_PBEN_BIT)
RCU_APB2EN_PAEN     = (1 << RCU_APB2EN_PAEN_BIT)
RCU_APB2EN_AFEN     = (1 << RCU_APB2EN_AFEN_BIT)

RCU_CFG0_PLLMF_Msk      = 0x203c0000
RCU_CFG0_AHBPSC_Msk     = 0xf0
RCU_CFG0_APB2PSC_Msk    = 0x3800
RCU_CFG0_APB1PSC_Msk    = 0x700
RCU_CFG0_SCS_Msk        = 0x3
RCU_CFG0_SCSS_Msk       = 0xc

RCU_CFG0_APB1PSC_Pos    = 8
RCU_CFG0_PLLMF_Pos      = 18
RCU_CFG0_PLLMF_4_Pos    = 29
RCU_CFG0_SCSS_Pos       = 2

RCU_CFG0_SCSS_PLL       = (2 << RCU_CFG0_SCSS_Pos)
RCU_CFG0_PLLMF_MUL24    = ( ((23 & 0xf) << RCU_CFG0_PLLMF_Pos) | (( 23 >> 4) << RCU_CFG0_PLLMF_4_Pos ))
RCU_CFG0_PLLMF_MUL27    = ( ((26 & 0xf) << RCU_CFG0_PLLMF_Pos) | (( 26 >> 4) << RCU_CFG0_PLLMF_4_Pos ))
RCU_CFG0_PLLSEL         = ( 1 << 13)
RCU_CTL_PLLEN           = ( 1 << 24 )
RCU_CFG0_APB1PSC_DIV2   = (4 << RCU_CFG0_APB1PSC_Pos)
RCU_CFG0_SCS_PLL        = 2
    
SPI0_BASE_ADDR          = 0x40013000
SPI1_BASE_ADDR          = 0x40003800  # GD32VF103 Manual: Section 18.11
SPI_STAT_TBE_BIT        = 1
SPI_STAT_TBE            = (1 << SPI_STAT_TBE_BIT)
SPI_STAT_TRANS_BIT      = 7
SPI_STAT_TRANS          = (1 << SPI_STAT_TRANS_BIT)
SPI_CTL0_OFFSET         = 0x00  # GD32VF103 Manual: Section 18.11.1
SPI_CTL1_OFFSET         = 0x04  # GD32VF103 Manual: Section 18.11.2
SPI_STAT_OFFSET         = 0x08  # GD32VF103 Manual: Section 18.11.3
SPI_DATA_OFFSET         = 0x0c  # GD32VF103 Manual: Section 18.11.4

SPI_CTL0_BDEN_BIT       = 15
SPI_CTL0_BDOEN_BIT      = 14
SPI_CTL0_SWNSSEN_BIT    =  9
SPI_CTL0_SWNSS_BIT      =  8
SPI_CTL0_SPIEN_BIT      =  6
SPI_CTL0_MSTMOD_BIT     =  2
SPI_CTL0_CKPL_BIT       =  1
SPI_CTL0_CKPH_BIT       =  0
SPI_CTL0_PSC_Pos        =  3

SPI_CTL0_BDEN       = (1 << SPI_CTL0_BDEN_BIT)
SPI_CTL0_BDOEN      = (1 << SPI_CTL0_BDOEN_BIT)
SPI_CTL0_SWNSSEN    = (1 << SPI_CTL0_SWNSSEN_BIT)
SPI_CTL0_SWNSS      = (1 << SPI_CTL0_SWNSS_BIT)
SPI_CTL0_SPIEN      = (1 << SPI_CTL0_SPIEN_BIT)
SPI_CTL0_MSTMOD     = (1 << SPI_CTL0_MSTMOD_BIT)
SPI_CTL0_CKPL       = (1 << SPI_CTL0_CKPL_BIT)
SPI_CTL0_CKPH       = (1 << SPI_CTL0_CKPH_BIT)

DP_CLOCKDIV_WRITE   =  (2 << SPI_CTL0_PSC_Pos)

MTIMER_BASE     = 0xD1000000

MTIMER_MTIME_LO_OFFSET      = 0x00
MTIMER_MTIME_HI_OFFSET      = 0x04
MTIMER_MTIMECMP_LO_OFFSET   = 0x08
MTIMER_MTIMECMP_HO_OFFSET   = 0x0c


# GD32VF103 Manual: page 111 
# LCD protocol
# PORT B
DP_DC_BIT   = 0 
DP_RST_BIT  = 1
DP_CS_BIT   = 2
DP_DC       = (1 << DP_DC_BIT) 
DP_RST      = (1 << DP_RST_BIT) 
DP_CS       = (1 << DP_CS_BIT) 

# PORT A
DP_SDA_BIT  = 7
DP_SCL_BIT  = 5
DP_SDA      = (1 << DP_SDA_BIT)
DP_SCL      = (1 << DP_SCL_BIT)

#LEDs
RED_LED_PIN = 13
GREEN_LED_PIN = 1
BLUE_LED_PIN = 2


# GD32VF103 Manual: Section 16.4
USART_BASE_ADDR_0 = 0x40013800
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

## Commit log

2022-10-19 Initial RP2040 device commit
    [BOM.csv, FXLoader_rev_A.brd, FXLoader_rev_A.sch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]
2022-10-30 Add data fetch capability
    - New version of PC code and PCFX code to send (and save) backup RAM (getbram, getbram.py)
    -- Includes roughed-in functions for sending blocks of memory to host
    - Note: you need to press a button on the controller to send data back
    - New version for RP2040 includes:
    -- support for the large LED for signalling;
    --- startup countdown ready when LED is white.
    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

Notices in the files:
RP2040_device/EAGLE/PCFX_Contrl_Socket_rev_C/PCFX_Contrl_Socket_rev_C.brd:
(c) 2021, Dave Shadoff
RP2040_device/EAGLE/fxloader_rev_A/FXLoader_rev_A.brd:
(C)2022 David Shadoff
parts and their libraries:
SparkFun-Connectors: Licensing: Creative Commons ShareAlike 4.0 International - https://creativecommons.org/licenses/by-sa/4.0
